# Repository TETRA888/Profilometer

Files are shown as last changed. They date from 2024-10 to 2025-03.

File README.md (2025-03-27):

#  <div align = "center">` Open Road Profiler (ORP) `</div>

 
 
 
 
 
 
 
 
 
 
 
An open-source system engineered to accurately map the deterioration of theoretical road designs proposed by Caltrans. Levergaing Class 3B precision laser, High load and Precision Stepper Motor Drivers, Encoders, Proximity sensors, and adjustable lighting to capture sub-millimeter road surface deformations under simulated traffic loads.

<div align="center">
  title image
</div>
<div align = "Center"> Figure 1.0 (Frame with Electronics) </div>

## Table of Contents
- [Purpose](#purpose)
- [How to Get Started](#how-to-get-started)
   - Parts List
- [Software System Design](#software-design)
- [Electrical System Design](#electrical-system-design)
  - Mounted Electronics
- [Mechanical Design](#mechanical-frame)
  - Assembled Frame
  - CAD model
- [Core Team](#core-team)
- [Documentation](#documentation-and-implementation)
- [Future Work](#future-work)
## Purpose

Purpose-built to work with the **Heavy Vehicle Simulator (HVS) system**, the ORP delivers end-to-end **systems engineering** for tracking pavement wear under simulated traffic conditions. Through repeated verification via external encoder sensors and validation via a 24/7 HVS Crew, the ORP system collects accurate degradation metrics, creating highly detailed point clouds and digital maps of road surfaces. These insights are pivotal in optimizing roads for the state of California. The end goal of this project is to enable all road research labs in the world with the ability to accurately assess how their road design degrades and performs overtime.

<p align="center">
  1-s2 0-S1996681417300354-gr6
</p>
<div align="center"> Figure 2.0 (Heavy Vehicle Simulator @ UCPRC Davis, CA 2025) </div>

<div style="text-align" align = "center">
  
  <div>Figure 2.1</div>

  
  <div>Figure 2.2</div>
</div>

<div style="text-align" align = "center"">
  Paving new Caltrans Proposed Road Designs @ UCPRC Davis, CA 2024
</div>

## How to Get Started
1. Clone the repository
```bash
$ git clone https://github.com/TETRA888/Profilometer.git
$ cd Profilometer
```
2. Download required dependencies 
```bash
$ pip install pyserial
$ pip install pillow
$ pip install pandas
$ pip install numpy
$ pip install matplotlib
$ pip install scipy
```

3. Adjust parameters for serial connection
* Inside /Profilometer/Code/Software/utilityFunctions.py
* Change the first argument for Serial '/dev/cu.usbmodem1422201' to your specific device port name
```python
   return serial.Serial('/dev/cu.usbmodem1422201', 115200, timeout=1)
```

5. Set up the hardware as described in the [Electrical System Design](#electrical-system-design) and [Mechanical Frame](#mechanical-frame) sections.
* [Parts list](https://docs.google.com/spreadsheets/d/1ZoPqY9_Fw6rnbfQ8UKPL65L5WncEJa40W8i2KiA_dJQ/edit?gid=0#gid=0)

## Software Design
The software is written in Python and C/C++ and provides tools for:
* Real-time data acquisition.
* Calibrating tools 
* Exporting data to formats like CSV and STL.

<p align="center">
 software design overview
 simple gui
</p>
<div align ="center"> Software Design Overview/Simple Gui 1.1</div>

## Electrical System Design

The profilometer consists of the following major electronic components:
* Sensors: Class 3B Precision laser, High Resolution Taiss Rotary Encoder, Inductive Proximity Sensor.
* Motors and Power: Nema 23 Stepper Motor, 600W Universal power supply, 5 DC-DC Buck Converters
*	Controllers: Arduino Mega microntroller with Raspberry Pi.

<p align="center">
  System Design
  Electrical Schematic
</p>
<div align="center"> Figure 3.1 High-Level Electrical System Design/Schematic  </div>

<p align="center">
  System Design
</p>
<div align="center"> Figure 3.2 (Assembled electronics) </div>

## Mechanical Frame

The mechanical frame of the profilometer serves as the structure that supports all the components, ensuring stability and precision during measurements. Below are the key aspects of the frame:

Material:
*	Constructed from high-strength aluminum alloy for durability and minimal thermal expansion.
*	Lightweight yet rigid enough to maintain precision during operation.

Design:
*	Modular design to allow for easy assembly and future upgrades.
*	Includes adjustable components to accommodate different sensor configurations and sample sizes.
  
Accessibility and Maintenance:
*	Open design for easy access to internal components, making maintenance and calibration straightforward.
*	Cable management system to keep wiring organized and prevent interference.

<p align="center">
  System Design
</p>
<div align = "Center" > Figure 4.1 (3D Blender Render) </div>

<p align="center">
  System Design
</p>
<div align = "Center" > Figure 4.2 (2nd Design Iteration Of Frame) </div>

# Core Team
- [<br /><sub><a href="https://github.com/TETRA888">Asad Melibaev</a></sub>](https://github.com/TETRA888/Profilometer)

- [<br /><sub><a href="https://github.com/adamhwu">Adam Wu</a></sub>](https://github.com/TETRA888/Profilometer)

# Documentation and Implementation:
1. [Wiki](https://github.com/TETRA888/Profilometer/wiki)

## Future Data Work Flow: pavement assessment via ML models trained on real world data and synthetic road data
* Real Road Data
To integrate ORP’s point cloud data into OpenUSD, the UsdGeomPoints schema will be used to represent sub-millimeter road surface deformations. Each point will include attributes like position (X,Y,ZX,Y,Z), normals, color, and custom degradation metrics. The data pipeline starts with preprocessing raw outputs from ORP (e.g., .txt, .ply), which are then converted into USD files using Python’s USD libraries. Surface reconstruction algorithms, such as Poisson reconstruction, can transform point clouds into detailed meshes stored as UsdGeomMesh. Time-series visualization of road degradation over simulated traffic cycles will leverage USD’s animation capabilities, enabling dynamic analysis. Once generated, USD files can be validated with tools like USDView or NVIDIA Omniverse for real-time visualization and shared for collaborative research. This pipeline enables scalable, accurate modeling of road performance, paving the way for global adoption in road research. Furthermore, OpenUSD could perhaps be even used to generate synthetic data. A similar usecase for generating synthetic data for license plate detection using OpenUSD is showcased here:https://developer.nvidia.com/blog/developing-smart-city-traffic-management-systems-with-openusd-and-synthetic-data/
* Synthetic road data could be generated after importing the profiled road data into OpenUSD. Randomization could be performed to generate more data for road edge cases, following this work flow from the official Nvidia docs:


## Acknowledgements

We would like to thank the following for their contributions to this project:
* Open-Source Libraries: This project uses several open-source libraries (check the dependencies section for a full list).
* Contributors: Thank you to everyone who has contributed to the development of this profilometer. See the contributors page for a list of all contributors.
* Issues: Feel free to open an issue in this GitHub repository for bug reports or feature requests.

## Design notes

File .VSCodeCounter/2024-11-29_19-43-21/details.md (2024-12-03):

# Details

Date : 2024-11-29 19:43:21

Directory d:\\Desktop\\ProfilometerProject\\Code

Total : 35 files,  631 codes, 125 comments, 223 blanks, all 979 lines

[Summary](results.md) / Details / [Diff Summary](diff.md) / [Diff Details](diff-details.md)

## Files
| filename | language | code | comment | blank | total |
| :--- | :--- | ---: | ---: | ---: | ---: |
| [Code/.VSCodeCounter/2024-11-29_19-42-19/details.md](/Code/.VSCodeCounter/2024-11-29_19-42-19/details.md) | Markdown | 27 | 0 | 6 | 33 |
| [Code/.VSCodeCounter/2024-11-29_19-42-19/diff-details.md](/Code/.VSCodeCounter/2024-11-29_19-42-19/diff-details.md) | Markdown | 9 | 0 | 6 | 15 |
| [Code/.VSCodeCounter/2024-11-29_19-42-19/diff.md](/Code/.VSCodeCounter/2024-11-29_19-42-19/diff.md) | Markdown | 12 | 0 | 7 | 19 |
| [Code/.VSCodeCounter/2024-11-29_19-42-19/results.json](/Code/.VSCodeCounter/2024-11-29_19-42-19/results.json) | JSON | 1 | 0 | 0 | 1 |
| [Code/.VSCodeCounter/2024-11-29_19-42-19/results.md](/Code/.VSCodeCounter/2024-11-29_19-42-19/results.md) | Markdown | 21 | 0 | 7 | 28 |
| [Code/.VSCodeCounter/2024-11-29_19-42-25/details.md](/Code/.VSCodeCounter/2024-11-29_19-42-25/details.md) | Markdown | 11 | 0 | 6 | 17 |
| [Code/.VSCodeCounter/2024-11-29_19-42-25/diff-details.md](/Code/.VSCodeCounter/2024-11-29_19-42-25/diff-details.md) | Markdown | 29 | 0 | 6 | 35 |
| [Code/.VSCodeCounter/2024-11-29_19-42-25/diff.md](/Code/.VSCodeCounter/2024-11-29_19-42-25/diff.md) | Markdown | 25 | 0 | 7 | 32 |
| [Code/.VSCodeCounter/2024-11-29_19-42-25/results.json](/Code/.VSCodeCounter/2024-11-29_19-42-25/results.json) | JSON | 1 | 0 | 0 | 1 |
| [Code/.VSCodeCounter/2024-11-29_19-42-25/results.md](/Code/.VSCodeCounter/2024-11-29_19-42-25/results.md) | Markdown | 14 | 0 | 7 | 21 |
| [Code/.VSCodeCounter/2024-11-29_19-42-37/details.md](/Code/.VSCodeCounter/2024-11-29_19-42-37/details.md) | Markdown | 27 | 0 | 6 | 33 |
| [Code/.VSCodeCounter/2024-11-29_19-42-37/diff-details.md](/Code/.VSCodeCounter/2024-11-29_19-42-37/diff-details.md) | Markdown | 29 | 0 | 6 | 35 |
| [Code/.VSCodeCounter/2024-11-29_19-42-37/diff.md](/Code/.VSCodeCounter/2024-11-29_19-42-37/diff.md) | Markdown | 24 | 0 | 7 | 31 |
| [Code/.VSCodeCounter/2024-11-29_19-42-37/results.json](/Code/.VSCodeCounter/2024-11-29_19-42-37/results.json) | JSON | 1 | 0 | 0 | 1 |
| [Code/.VSCodeCounter/2024-11-29_19-42-37/results.md](/Code/.VSCodeCounter/2024-11-29_19-42-37/results.md) | Markdown | 21 | 0 | 7 | 28 |
| [Code/Firmware/main/.VSCodeCounter/2024-11-27_22-10-14/details.md](/Code/Firmware/main/.VSCodeCounter/2024-11-27_22-10-14/details.md) | Markdown | 22 | 0 | 6 | 28 |
| [Code/Firmware/main/.VSCodeCounter/2024-11-27_22-10-14/diff-details.md](/Code/Firmware/main/.VSCodeCounter/2024-11-27_22-10-14/diff-details.md) | Markdown | 9 | 0 | 6 | 15 |
| [Code/Firmware/main/.VSCodeCounter/2024-11-27_22-10-14/diff.md](/Code/Firmware/main/.VSCodeCounter/2024-11-27_22-10-14/diff.md) | Markdown | 12 | 0 | 7 | 19 |
| [Code/Firmware/main/.VSCodeCounter/2024-11-27_22-10-14/results.json](/Code/Firmware/main/.VSCodeCounter/2024-11-27_22-10-14/results.json) | JSON | 1 | 0 | 0 | 1 |
| [Code/Firmware/main/.VSCodeCounter/2024-11-27_22-10-14/results.md](/Code/Firmware/main/.VSCodeCounter/2024-11-27_22-10-14/results.md) | Markdown | 15 | 0 | 7 | 22 |
| [Code/Firmware/main/encoderOutput.cpp](/Code/Firmware/main/encoderOutput.cpp) | C++ | 27 | 11 | 8 | 46 |
| [Code/Firmware/main/encoderOutput.hpp](/Code/Firmware/main/encoderOutput.hpp) | C++ | 11 | 0 | 4 | 15 |
| [Code/Firmware/main/endStopOutput.cpp](/Code/Firmware/main/endStopOutput.cpp) | C++ | 11 | 6 | 7 | 24 |
| [Code/Firmware/main/endStopOutput.hpp](/Code/Firmware/main/endStopOutput.hpp) | C++ | 8 | 0 | 5 | 13 |
| [Code/Firmware/main/laserOutput.cpp](/Code/Firmware/main/laserOutput.cpp) | C++ | 12 | 6 | 5 | 23 |
| [Code/Firmware/main/laserOutput.hpp](/Code/Firmware/main/laserOutput.hpp) | C++ | 9 | 0 | 4 | 13 |
| [Code/Firmware/main/main.ino](/Code/Firmware/main/main.ino) | Arduino | 35 | 10 | 6 | 51 |
| [Code/Firmware/main/statusIndicators.cpp](/Code/Firmware/main/statusIndicators.cpp) | C++ | 46 | 15 | 9 | 70 |
| [Code/Firmware/main/statusIndicators.hpp](/Code/Firmware/main/statusIndicators.hpp) | C++ | 12 | 0 | 6 | 18 |
| [Code/Firmware/main/stepperMotorControl.cpp](/Code/Firmware/main/stepperMotorControl.cpp) | C++ | 22 | 16 | 12 | 50 |
| [Code/Firmware/main/stepperMotorControl.hpp](/Code/Firmware/main/stepperMotorControl.hpp) | C++ | 12 | 0 | 4 | 16 |
| [Code/Firmware/main/utilityFunctions.cpp](/Code/Firmware/main/utilityFunctions.cpp) | C++ | 51 | 17 | 18 | 86 |
| [Code/Firmware/main/utilityFunctions.hpp](/Code/Firmware/main/utilityFunctions.hpp) | C++ | 16 | 0 | 4 | 20 |
| [Code/Software/gui.py](/Code/Software/gui.py) | Python | 21 | 20 | 16 | 57 |
| [Code/Software/utilityFunctions.py](/Code/Software/utilityFunctions.py) | Python | 27 | 24 | 11 | 62 |

[Summary](results.md) / Details / [Diff Summary](diff.md) / [Diff Details](diff-details.md)

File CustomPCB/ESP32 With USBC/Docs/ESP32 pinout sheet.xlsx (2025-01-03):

1 | GND_01
2 | GND_02
3 | 3V3
4 | GPIO0/RTC_GPIO0
5 | GPIO1/RTC_GPIO1/TOUCH1/ADC1_CH0
6 | GPIO2/RTC_GPIO2/TOUCH2/ADC1_CH1
7 | GPIO3/RTC_GPIO3/TOUCH3/ADC1_CH2
8 | GPIO4/RTC_GPIO4/TOUCH4/ADC1_CH3
9 | GPIO5/RTC_GPIO5/TOUCH5/ADC1_CH4
10 | GPIO6/RTC_GPIO6/TOUCH6/ADC1_CH5
11 | GPIO7/RTC_GPIO7/TOUCH7/ADC1_CH6
12 | GPIO8/RTC_GPIO8/TOUCH8/ADC1_CH7/SUBSPICS1
13 | GPIO9/RTC_GPIO9/TOUCH9/ADC1_CH8/FSPIHD/SUBSPIHD
14 | GPIO10/RTC_GPIO10/TOUCH10/ADC1_CH9/FSPICS0/FSPIIO4/SUBSPICS0
15 | GPIO11/RTC_GPIO11/TOUCH11/ADC2_CH0/FSPID/FSPIIO5/SUBSPID
16 | GPIO12/RTC_GPIO12/TOUCH12/ADC2_CH1/FSPICLK/FSPIIO6/SUBSPICLK
17 | GPIO13/RTC_GPIO13/TOUCH13/ADC2_CH2/FSPIQ/FSPIIO7/SUBSPIQ
18 | GPIO14/RTC_GPIO14/TOUCH14/ADC2_CH3/FSPIWP/FSPIDQS/SUBSPIWP
19 | GPIO15/RTC_GPIO15/U0RTS/ADC2_CH4/XTAL_32K_P
20 | GPIO16/RTC_GPIO16/U0CTS/ADC2_CH5/XTAL_32K_N
21 | GPIO17/RTC_GPIO17/U1TXD/ADC2_CH6
22 | GPIO18/RTC_GPIO18/U1RXD/ADC2_CH7/CLK_OUT3
23 | USB_D-/RTC_GPIO19/GPIO19/U1RTS/ADC2_CH8/CLK_OUT2
24 | USB_D+/RTC_GPIO20/GPIO20/U1CTS/ADC2_CH9/CLK_OUT1
25 | GPIO21/RTC_GPIO21
26 | GPIO26/SPICS1
27 | GPIO47/SPICLK_P_DIFF/SUBSPICLK_P_DIFF
28 | GPIO33/SPIIO4/FSPIHD/SUBSPIHD
29 | GPIO34/SPIIO5/FSPICS0/SUBSPICS0
30 | GPIO48/SPICLK_N_DIFF/SUBSPICLK_N_DIFF
31 | GPIO35/SPIIO6/FSPID/SUBSPID
32 | GPIO36/SPIIO7/FSPICLK/SUBSPICLK
33 | GPIO37/SPIDQS/FSPIQ/SUBSPIQ
34 | GPIO38/FSPIWP/SUBSPIWP
35 | MTCK/GPIO39/CLK_OUT3/SUBSPICS1
36 | MTDO/GPIO40/CLK_OUT2
37 | MTDI/GPIO41/CLK_OUT1
38 | MTMS/GPIO42
39 | U0TXD/GPIO43/CLK_OUT1
40 | U0RXD/GPIO44/CLK_OUT2
41 | GPIO45
42 | GND
43 | GND
44 | GPIO46
45 | EN
46 | GND_46
47 | GND_47
48 | GND_48
49 | GND_49
50 | GND_50
51 | GND_51
52 | GND_52
53 | GND_53
54 | GND_54
55 | GND_55
56 | GND_56
57 | GND_57
58 | GND_58
59 | GND_59
60 | GND_60
61 | GND_61
62 | GND_62
63 | GND_63
64 | GND_64
65 | GND_65
66 | GND_66
67 | GND_67
68 | GND_68
69 | GND_69
70 | GND_70
71 | GND_71
72 | GND_72
73 | GND_73

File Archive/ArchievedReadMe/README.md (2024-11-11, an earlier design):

#  <div align="center"> Open Road Profiler (ORP) </div>

The **Open Road Profiler (ORP)** is an advanced, open-source system engineered to map the degradation of theoretical road designs for Caltrans. This precision gantry platform leverages a robust integration of **computer vision**, **LiDAR sensing**, and **optical measurement** technologies, including a Garmin LiDAR-Lite v3HP, a 64MP high-resolution camera, and a Class II precision laser, to capture sub-millimeter road surface deformations under simulated traffic loads.

## Purpose

Purpose-built to work with the **Heavy Vehicle Simulator (HVS) system**, the ORP delivers end-to-end **systems engineering** for tracking pavement wear under simulated traffic conditions. Through repeated verification via external encoder sensors and validation via a 24/7 HVS Crew, the ORP system collects accurate degradation metrics, creating highly detailed point clouds and digital maps of road surfaces. These insights are pivotal in optimizing roads for the state of California. The end goal of this project is to enable all road research labs in the world with the ability to accurately assess how their road design degrades and performs overtime.

## Project Leadership

Led by **Asad Melibaev**, the project emphasizes a modular, scalable design, ensuring smooth integration with existing HVS systems and adaptability to future sensing technologies. With support from a dedicated team of R&D engineers, PhD researchers, and machinists, the ORP’s goal is to enable precise, actionable data analysis to inform road composition improvements and advance Caltrans' pavement research efforts.

<p align="center">
  1-s2 0-S1996681417300354-gr6
</p>
<div align="center"> Figure 1.0 (Heavy Vehicle Simulator) </div>

## Key Contributors

### Core Team
- **Asad Melibaev**  
  *(Systems Lead)*  
  [GitHub Profile](https://github.com/TETRA888)

### Help, Advice and Guidance from
- **Andrew Cobb**  
  *(Sr. Machinst)*  

- **Kin Yen**  
  *(Sr. Development Engineer)*  

- **Stephanus Louw**  
  *(Lead Geotechnical Engineer)*

- **Rauf Zokhrabov**  
  *(Documentation Assistant)*
  *(University of Illinois Urbana-Champaign)*
  
### <div align = "center"> Acknowledgments </div>
I would like to express my sincere gratitude to my Electrical Engineering professors and faculty members at UC Davis for their invaluable support in designing the system and deepening my understanding of circuit design. Their expertise and guidance have been instrumental in the development of this project.
  
## <div align = "center"> Collaborating Institutions </div>
PIC_Logo_Version3-1
cee_logo_125px
ece_logo_125px

# <div align="center"> Asad's Workflow And Design Approach </div>
<p align = "center">
1-s2 0-S1996681417300354-gr6
</p>

### <div align="center"> Figure 2.0 (Asad's Workflow) </div>

# <div align="center"> High-Level Multi System Integration Overview </div>
<p align = "center">
1-s2 0-S1996681417300354-gr6
</p>

### <div align="center"> Figure 3.0 (The connection of different subsystems to collect data on stress tested roads) </div>

# <div align ="center"> High-Level Electrical System Design Overview </div>
ElectricalSystemDiagram(1)
### <div align="center"> Figure 4.0 (Abstract overview of the electronic connections by A.M) </div>

# <div align ="center"> Electronic Schematic Overview </div>

### <div align="center"> Figure 4.1 (Schematic of the single axial gantry control by A.M) </div>

# <div align ="center"> Assembled Data Acquisition Electronics Overview </div>

### <div align="center"> Figure 4.2 (The nervous system of the gantry assembled by A.M) </div>

# <div align ="center"> High-Level Software System Design Overview </div>
<p align = "center">
1-s2 0-S1996681417300354-gr6
</p>

### <div align="center"> Figure 5.0 (Data flow) </div>

## Sample Software Code
```python
import serial
import time
import numpy as np
import open3d as o3d

# Open the serial connection
ser = serial.Serial('/dev/ACM1', 115200, timeout=1)
time.sleep(2)  # Give the connection a moment to initialize

# Send the start command to the Arduino
ser.write(b'START\n')
print("Start command sent to Arduino")

# Function to load point data from a text file
def load_point_data(file_path):
    points_data = np.loadtxt(file_path, delimiter=' ', dtype=float)
    return points_data

# Read the data sent back by the Arduino
data_points = []

while True:
    if ser.in_waiting > 0:
        line = ser.readline().decode('utf-8').strip()
        if line.startswith("DATA:"):
            try:
                _, values = line.split("DATA:")
                x, y, z = map(float, values.split(","))
                print(f"X: {x}, Y: {y}, Z: {z}")
                # Store the data points
                data_points.append((x, y, z))
            except ValueError:
                print("Parsing error!")

    # Break out of the loop if you want to stop reading (you can define a condition)
    if len(data_points) >= 100:  # for example, stop after 100 points
        break

# Convert collected points to NumPy array
points_data = np.array(data_points)

# Ensure the data is in the correct shape
if points_data.shape[1] != 3:
    raise ValueError("Each line in the data must contain 3 values: x, y, z")

# Create Open3D point cloud
pcd = o3d.geometry.PointCloud()
pcd.points = o3d.utility.Vector3dVector(points_data)

# Estimate normals for the point cloud
pcd.estimate_normals(search_param=o3d.geometry.KDTreeSearchParamHybrid(radius=0.1, max_nn=30))

# Perform Poisson reconstruction
mesh, densities = o3d.geometry.TriangleMesh.create_from_point_cloud_poisson(pcd, depth=9)

# Visualize the result
o3d.visualization.draw_geometries([mesh])

# Optionally save the mesh to a file
o3d.io.write_triangle_mesh("output_mesh.ply", mesh)

# Close the serial connection
ser.close()
```

## Sample Firmware Code
```cpp
/*
* Submilimeter X-Axis gantry control code by Asad Melibaev
* This code will be broken down into a multi-file program once debugging and further testing is completed
*/

#include <AccelStepper.h> // Stepper motor library with fine controls
#include <math.h>
#define PI 3.14159265358979323846
#define RC 0.1466275659824047 // Rotary calibration constant calculated by A.M
#define CN 1.33351439541 // Conversion constant calculated by A.M

/*
* Connect corresponding pins to the DM542 stepper motor driver 
*/
const int stepPin = 13;    // STEP pin connected to pin 13
const int dirPin = 12;     // DIR pin connected to pin 12
const int enablePin = 9;   // EN pin connected to pin 9 (optional)

/*
Connect corresponding encoder pins to the microcontroller
*/
const int encoderPinA = 21; // Encoder Channel A
const int encoderPinB = 20; // Encoder Channel B

/*
* Create the stepper object with driver mode enabled by setting the first param to 1
*/
AccelStepper stepper(1, stepPin, dirPin);

/*
* Encoder variables will be constantly changing therefore are set to volatile
* This ensures the compiler does not optimize or store stuff in cache
*/
volatile long encoderPosition = 0; // Current position
volatile bool lastAState = LOW;     // Last state of encoder pin A
volatile int offsetFromExpected = 0;

/*
* Update encoder vars as soon as position changes
*/
void updateEncoder() {
    bool currentAState = digitalRead(encoderPinA);
    bool currentBState = digitalRead(encoderPinB);

    if (currentAState != lastAState) { // Only update on change of state
        if (currentBState == currentAState) {
            encoderPosition++; // Clockwise
        } else {
            encoderPosition--; // Counterclockwise
        }
    }

    lastAState = currentAState; // Update last state

    // Void returns nothin 
}

/*
* Adjusts stepper motor location to correct an offset caused during movement
* @param offsetFromExpected is the amount of steps that the position is offset by
*/
void correctLocation(int offsetFromExpected){
    stepper.moveTo(offsetFromExpected); // Set target position
    while (stepper.distanceToGo() != 0) { // Move until the target position is reached and verified by encoder
        stepper.run(); // Run the stepper motor
    }

    // Void returns nothing
}

/*
* This function verifies that the accuracy is within the submilimeter tolerence and if its not it adjusts the offsetFromExpected value
@ param distance: is the distance in mm
@ param pulses: is the amount of pulses that have been sent to the stepper motor
*/
void verifiedAccuracy(int distance, int pulses){
  double TOLERANCE = 0.1; // in mm

  if (fabs(encoderPosition * RC - distance) > TOLERANCE){
    offsetFromExpected = pulses*CN - encoderPosition;
  }

  // Void Returns nothing
}

/*
* This function moves the rail by the specified distance in mm
@param distance: Is the distance that it will move in mm
*/
void move_rail_x(int distance) {
    int pulses = (distance / (2 * PI * 28)) * 3200; // Calculate pulses for the given distance // 0.1466 mm per pulse to be exact
    stepper.moveTo(pulses); // Set target position
    while (stepper.distanceToGo() != 0) { // Move until the target position is reached and verified by encoder
        stepper.run(); // Run the stepper motor
    }

    /*
    verifiedAccuracy(distance, pulses);

    if (offsetFromExpected != 0){
      correctLocation(offsetFromExpected);
      offsetFromExpected = 0;
    }
    */

    // Void returns nothing
}

/*
* Initialize required pins, interrupts, and serial communication between the PC and microcontroller
*/
void setup() {
    Serial.begin(115200);
    pinMode(enablePin, OUTPUT); // Set the enable pin as an output
    digitalWrite(enablePin, LOW); // Enable the driver
    
    // Set encoder pins as inputs with pull-ups
    pinMode(encoderPinA, INPUT_PULLUP);
    pinMode(encoderPinB, INPUT_PULLUP);
    
    // Attach interrupts for encoder channels
    attachInterrupt(digitalPinToInterrupt(encoderPinA), updateEncoder, CHANGE);
    attachInterrupt(digitalPinToInterrupt(encoderPinB), updateEncoder, CHANGE);

    // Set the maximum speed and acceleration
    stepper.setMaxSpeed(2000); // 2000mm/s
    stepper.setAcceleration(1000); // 400mm/s^2

    // Void returns nothing
}

/*
* Main function where the gantry will move
* Currently setup to check calibration
*/
void loop() {
    int distance = 500; // Distance is in millimeters (1 meter)
    move_rail_x(distance); // Move the rail by the specified distance

    // Optionally, print encoder position for debugging
    Serial.print("Encoder Position: ");
    Serial.print(encoderPosition*RC);
    Serial.println(" mm");
    
    delay(1000); // Wait for 1 second before the next move

    // Void returns nothing
}
```

# <div align ="center"> Mechanical Frame CAD Design Overview </div>
370409415-1df8b744-70b0-4bfa-a11d-afa3a9b27c9c
### <div align = "Center" > Figure 6.0 (3D Blender Render) </div>

## Assembled Sample Frame

### <div align = "Center" > Figure 6.1 (2nd Design Iteration Of Frame) </div>

# Documentation and Implementation:
1. [Wiki](https://github.com/TETRA888/Profilometer/wiki)

# Tech Stack and Specs:
 
 
 
 
 
 
 
 

# Parts:
1. [Exact quantities and parts needed for single axial system](https://docs.google.com/spreadsheets/d/1ZoPqY9_Fw6rnbfQ8UKPL65L5WncEJa40W8i2KiA_dJQ/edit?gid=0#gid=0)
2. [Parts list draft](https://docs.google.com/document/d/1qKMDZtSdquMjX08xfJKCa0uS36UHgNZ3eyHph81zQOM/edit)

# Profiler from 30 years ago
<p align="center"> 

</p>

### <div align = "Center" > Figure 7.0 (The First Profiler) </div>

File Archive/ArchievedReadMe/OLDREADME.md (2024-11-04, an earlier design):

# High-Level Multi System Integration Overview
Systems Diagram(1)

# High-Level Electrical System Design Overview
Electronic System Overview(1)

# High-Level Software System Design Overview
High Level Software

# Low-Level Embedded Software System Design Overview
Software Design

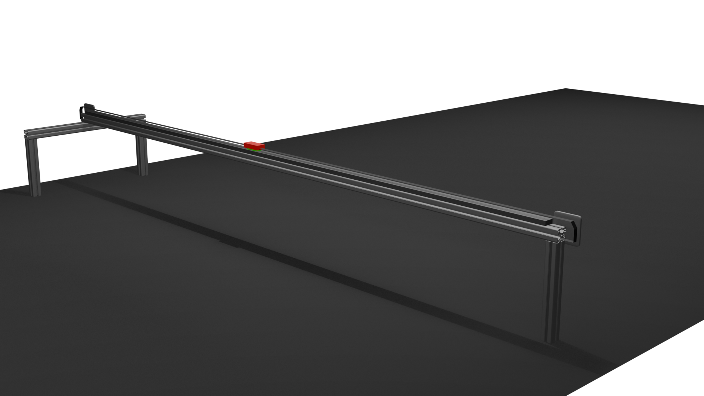
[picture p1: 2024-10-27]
Renders/AngledView.png

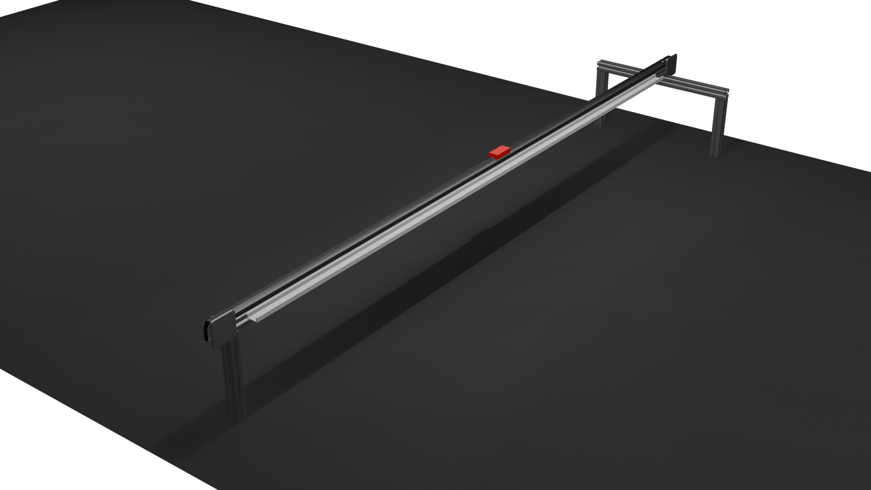
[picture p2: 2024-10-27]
Renders/TopDownView.png

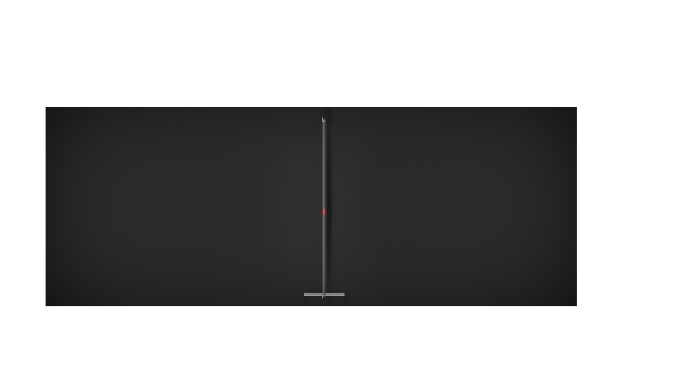
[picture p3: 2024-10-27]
Renders/TopView.png

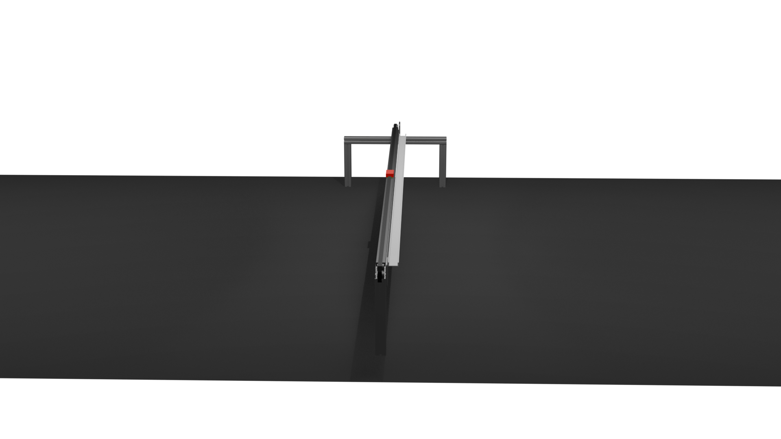
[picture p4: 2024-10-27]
Renders/Sideview.png

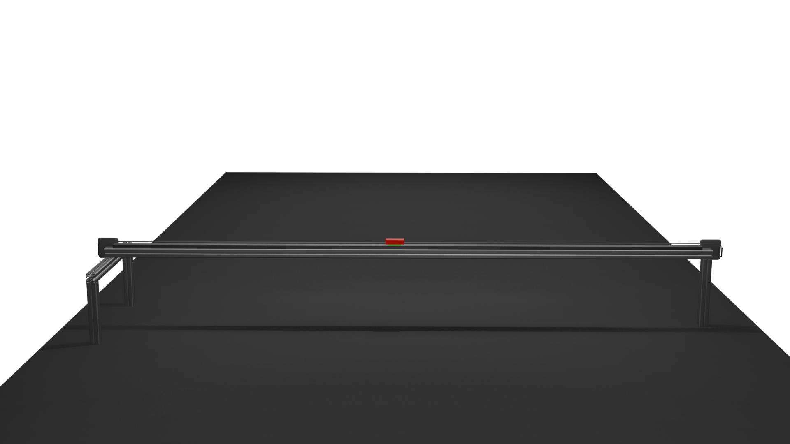
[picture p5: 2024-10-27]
Renders/FrontView.png

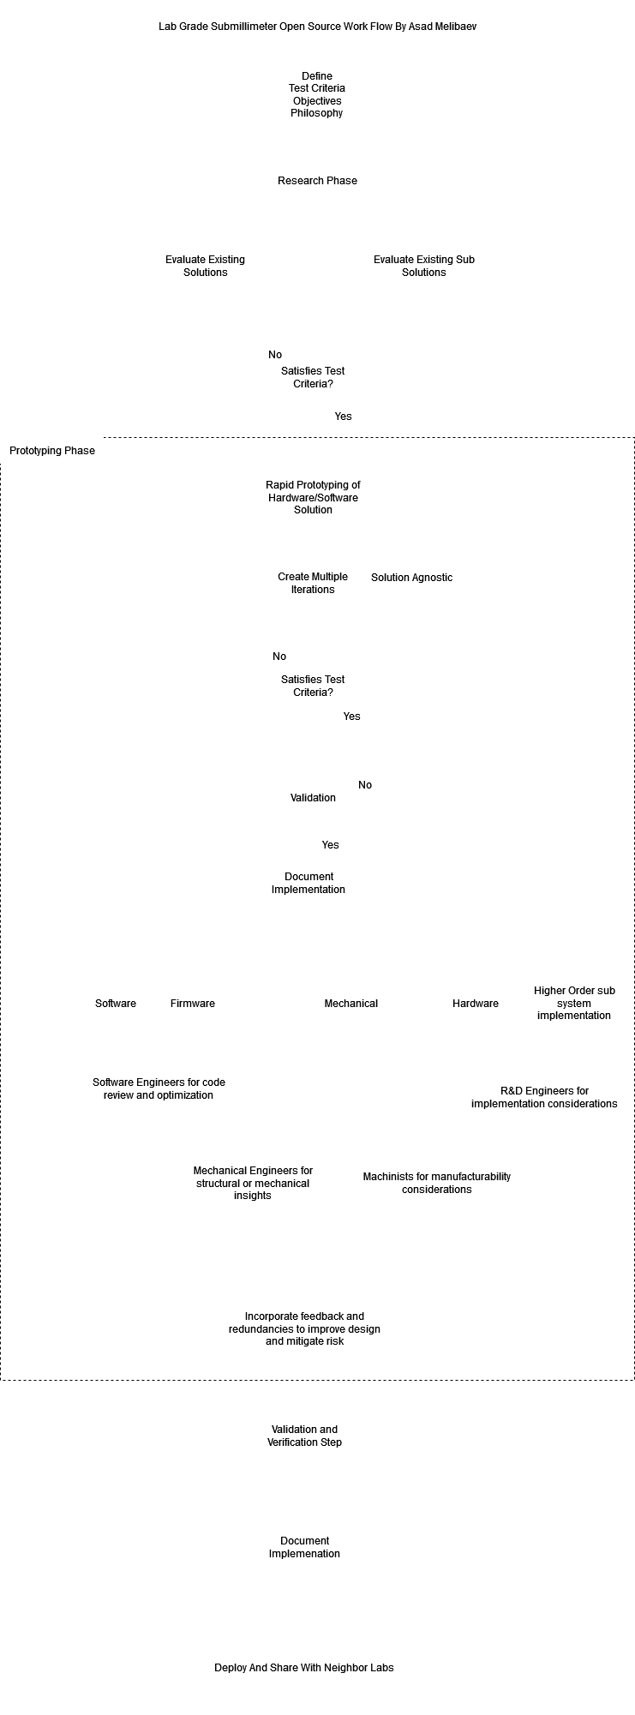
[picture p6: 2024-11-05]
FlowDiagrams/ProcessDiagram.png

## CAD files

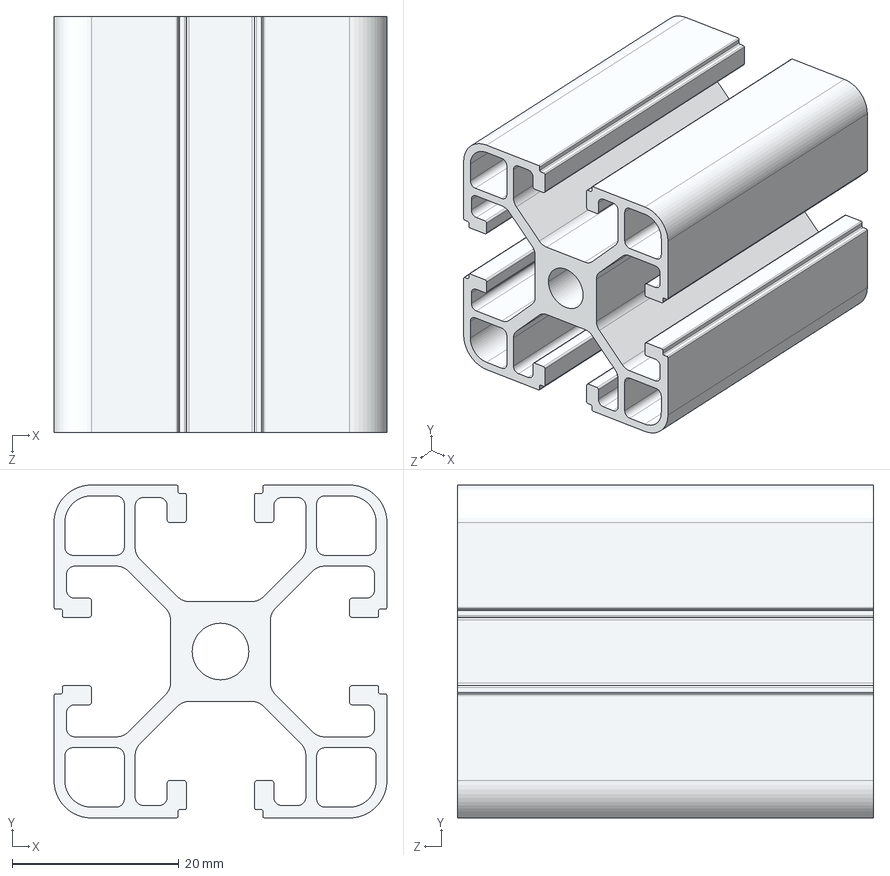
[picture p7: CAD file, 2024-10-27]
CADModels/4040 Aluminum Extrusion Profile.STEP
40.0 x 40.0 x 50.0 mm

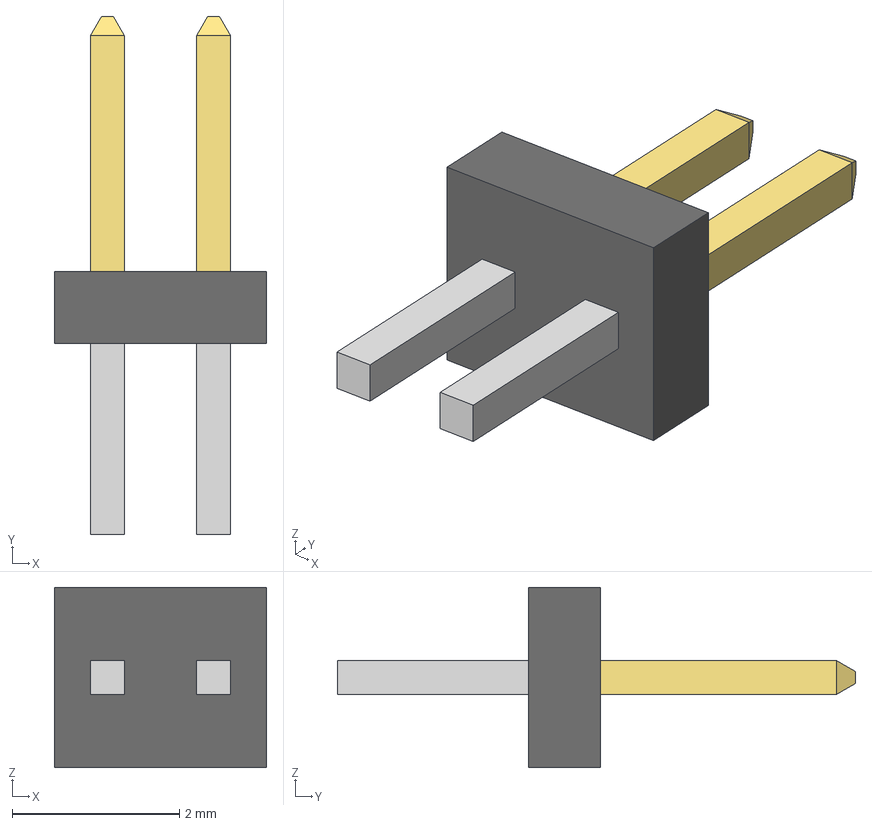
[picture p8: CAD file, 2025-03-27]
CustomPCB/ESP32 With USBC/3D/FTS-102-01-F-S.stp
2.54 x 6.20 x 2.16 mm
FTS-102-01-F-S_body
FTS-102-01-F-S_pins1
FTS-102-01-F-S_pins2

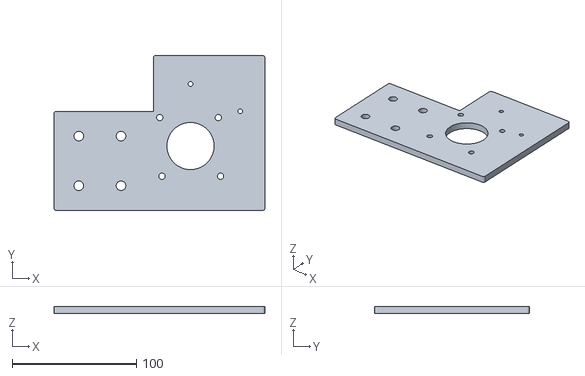
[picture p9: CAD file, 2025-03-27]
ProfilerBrackets/RightSideBracket.stl
170.0 x 125.0 x 6.00

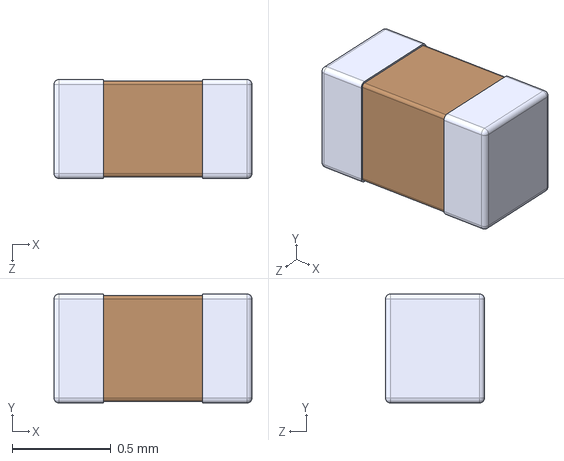
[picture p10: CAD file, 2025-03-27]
CustomPCB/ESP32 With USBC/3D/CL05A105KL5NRNC.step
1.00 x 0.55 x 0.5 mm

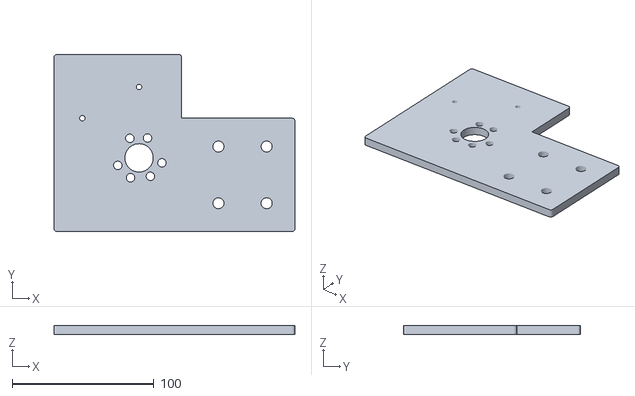
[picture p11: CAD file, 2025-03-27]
ProfilerBrackets/LeftSideBracket.stl
170.0 x 125.0 x 6.00

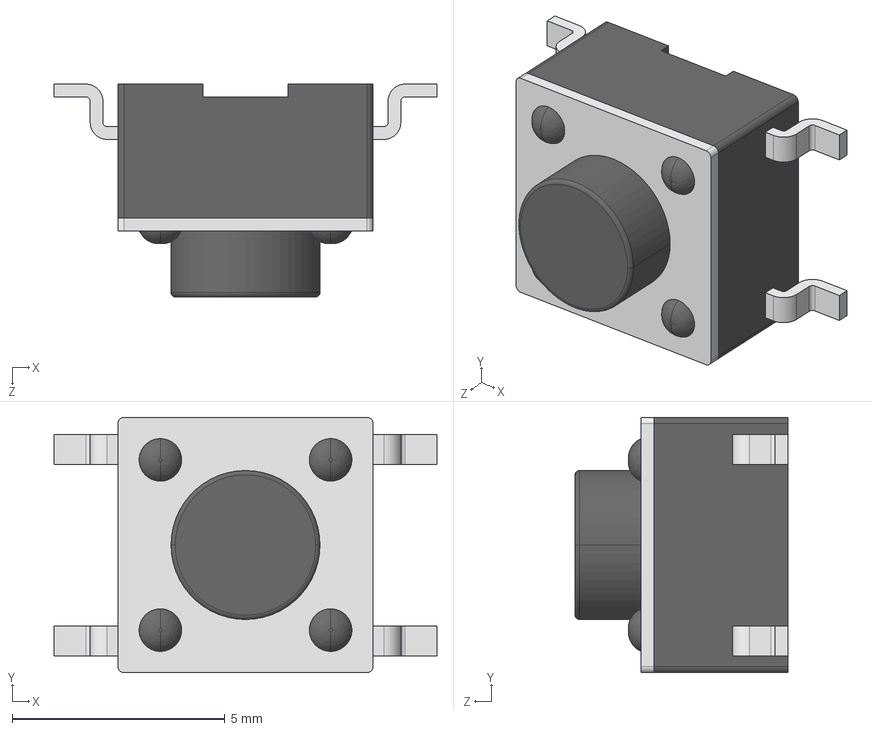
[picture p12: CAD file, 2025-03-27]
CustomPCB/ESP32 With USBC/3D/User Library-PTS645SL50SMTR92-LFS.STEP
9.00 x 6.00 x 5.00 mm

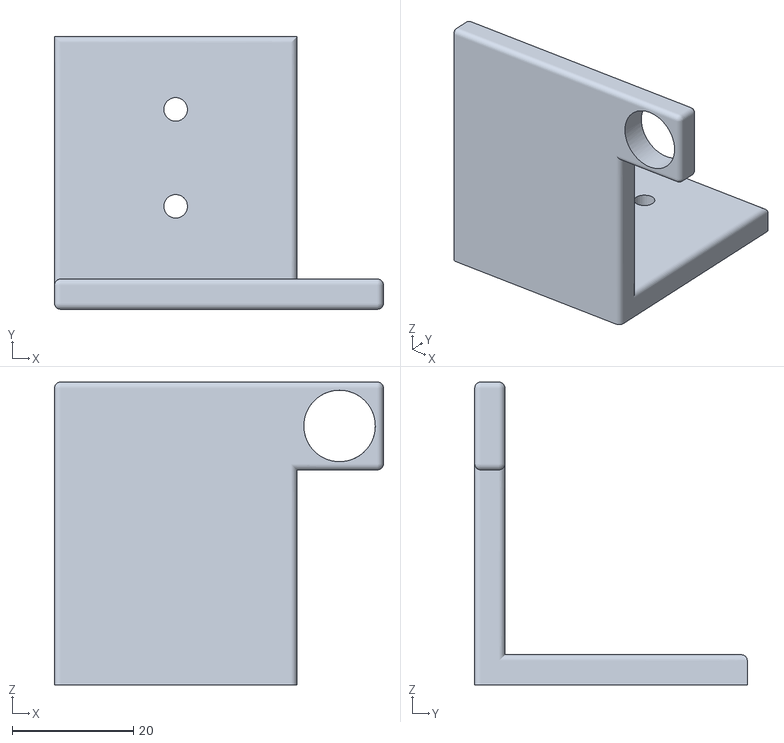
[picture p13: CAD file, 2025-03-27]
ProfilerBrackets/LeftProximityBracket.stl
54.3 x 45.0 x 50.0

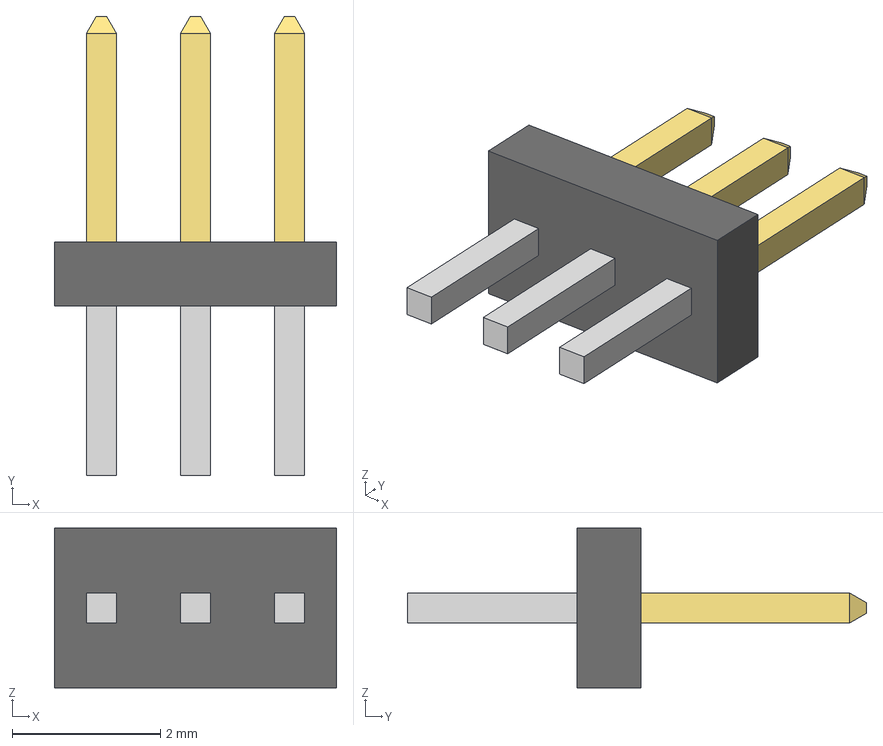
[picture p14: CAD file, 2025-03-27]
CustomPCB/ESP32 With USBC/3D/FTS-103-01-F-S.stp
3.81 x 6.20 x 2.16 mm
FTS-103-01-F-S_body
FTS-103-01-F-S_pins1
FTS-103-01-F-S_pins2

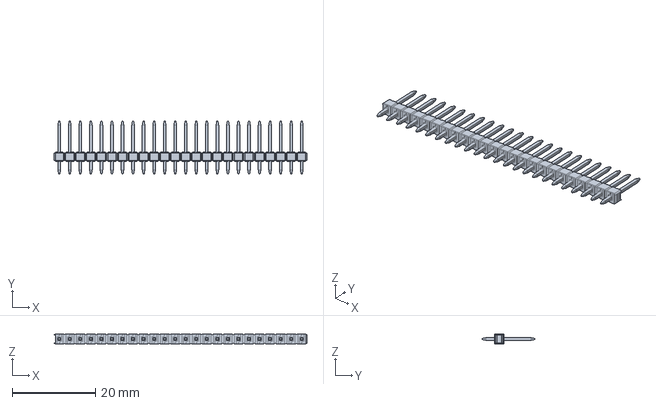
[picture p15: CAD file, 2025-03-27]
CustomPCB/ESP32 With USBC/3D/022284245.stp
61.0 x 12.8 x 2.49 mm

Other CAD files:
ProfilerBrackets/RightProximityBracket.stl
CADModels/4040 Aluminum Extrusion Profile.stl
CADModels/Model.blend

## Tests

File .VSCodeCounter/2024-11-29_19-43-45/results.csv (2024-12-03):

filename | "language" | "Python" | "C++" | "Arduino" | "Markdown" | "JSON" | "comment" | "blank" | "total"
d:\Desktop\ProfilometerProject\Code\Firmware\main\.VSCodeCounter\2024-11-27_22-10-14\details.md | "Markdown" | 0 | 0 | 0 | 22 | 0 | 0 | 6 | 28
d:\Desktop\ProfilometerProject\Code\Firmware\main\.VSCodeCounter\2024-11-27_22-10-14\diff-details.md | "Markdown" | 0 | 0 | 0 | 9 | 0 | 0 | 6 | 15
d:\Desktop\ProfilometerProject\Code\Firmware\main\.VSCodeCounter\2024-11-27_22-10-14\diff.md | "Markdown" | 0 | 0 | 0 | 12 | 0 | 0 | 7 | 19
d:\Desktop\ProfilometerProject\Code\Firmware\main\.VSCodeCounter\2024-11-27_22-10-14\results.json | "JSON" | 0 | 0 | 0 | 0 | 1 | 0 | 0 | 1
d:\Desktop\ProfilometerProject\Code\Firmware\main\.VSCodeCounter\2024-11-27_22-10-14\results.md | "Markdown" | 0 | 0 | 0 | 15 | 0 | 0 | 7 | 22
d:\Desktop\ProfilometerProject\Code\Firmware\main\encoderOutput.cpp | "C++" | 0 | 27 | 0 | 0 | 0 | 11 | 8 | 46
d:\Desktop\ProfilometerProject\Code\Firmware\main\encoderOutput.hpp | "C++" | 0 | 11 | 0 | 0 | 0 | 0 | 4 | 15
d:\Desktop\ProfilometerProject\Code\Firmware\main\endStopOutput.cpp | "C++" | 0 | 11 | 0 | 0 | 0 | 6 | 7 | 24
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

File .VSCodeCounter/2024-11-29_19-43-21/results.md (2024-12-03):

# Summary

Date : 2024-11-29 19:43:21

Directory d:\\Desktop\\ProfilometerProject\\Code

Total : 35 files,  631 codes, 125 comments, 223 blanks, all 979 lines

Summary / [Details](details.md) / [Diff Summary](diff.md) / [Diff Details](diff-details.md)

## Languages
| language | files | code | comment | blank | total |
| :--- | ---: | ---: | ---: | ---: | ---: |
| Markdown | 16 | 307 | 0 | 104 | 411 |
| C++ | 12 | 237 | 71 | 86 | 394 |
| Python | 2 | 48 | 44 | 27 | 119 |
| Arduino | 1 | 35 | 10 | 6 | 51 |
| JSON | 4 | 4 | 0 | 0 | 4 |

## Directories
| path | files | code | comment | blank | total |
| :--- | ---: | ---: | ---: | ---: | ---: |
| . | 35 | 631 | 125 | 223 | 979 |
| .VSCodeCounter | 15 | 252 | 0 | 78 | 330 |
| .VSCodeCounter\\2024-11-29_19-42-19 | 5 | 70 | 0 | 26 | 96 |
| .VSCodeCounter\\2024-11-29_19-42-25 | 5 | 80 | 0 | 26 | 106 |
| .VSCodeCounter\\2024-11-29_19-42-37 | 5 | 102 | 0 | 26 | 128 |
| Firmware | 18 | 331 | 81 | 118 | 530 |
| Firmware\\main | 18 | 331 | 81 | 118 | 530 |
| Firmware\\main (Files) | 13 | 272 | 81 | 92 | 445 |
| Firmware\\main\\.VSCodeCounter | 5 | 59 | 0 | 26 | 85 |
| Firmware\\main\\.VSCodeCounter\\2024-11-27_22-10-14 | 5 | 59 | 0 | 26 | 85 |
| Software | 2 | 48 | 44 | 27 | 119 |

Summary / [Details](details.md) / [Diff Summary](diff.md) / [Diff Details](diff-details.md)

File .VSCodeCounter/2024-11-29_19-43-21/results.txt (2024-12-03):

Date : 2024-11-29 19:43:21
Directory : d:\Desktop\ProfilometerProject\Code
Total : 35 files,  631 codes, 125 comments, 223 blanks, all 979 lines

Languages
+----------+------------+------------+------------+------------+------------+
| language | files      | code       | comment    | blank      | total      |
+----------+------------+------------+------------+------------+------------+
| Markdown |         16 |        307 |          0 |        104 |        411 |
| C++      |         12 |        237 |         71 |         86 |        394 |
| Python   |          2 |         48 |         44 |         27 |        119 |
| Arduino  |          1 |         35 |         10 |          6 |         51 |
| JSON     |          4 |          4 |          0 |          0 |          4 |
+----------+------------+------------+------------+------------+------------+

Directories
+------------------------------------------------------------------------------------------------------+------------+------------+------------+------------+------------+
| path                                                                                                 | files      | code       | comment    | blank      | total      |
+------------------------------------------------------------------------------------------------------+------------+------------+------------+------------+------------+
| .                                                                                                    |         35 |        631 |        125 |        223 |        979 |
| .VSCodeCounter                                                                                       |         15 |        252 |          0 |         78 |        330 |
| .VSCodeCounter\2024-11-29_19-42-19                                                                   |          5 |         70 |          0 |         26 |         96 |
| .VSCodeCounter\2024-11-29_19-42-25                                                                   |          5 |         80 |          0 |         26 |        106 |
| .VSCodeCounter\2024-11-29_19-42-37                                                                   |          5 |        102 |          0 |         26 |        128 |
| Firmware                                                                                             |         18 |        331 |         81 |        118 |        530 |
| Firmware\main                                                                                        |         18 |        331 |         81 |        118 |        530 |
| Firmware\main (Files)                                                                                |         13 |        272 |         81 |         92 |        445 |
| Firmware\main\.VSCodeCounter                                                                         |          5 |         59 |          0 |         26 |         85 |
| Firmware\main\.VSCodeCounter\2024-11-27_22-10-14                                                     |          5 |         59 |          0 |         26 |         85 |
| Software                                                                                             |          2 |         48 |         44 |         27 |        119 |
+------------------------------------------------------------------------------------------------------+------------+------------+------------+------------+------------+

Files
+------------------------------------------------------------------------------------------------------+----------+------------+------------+------------+------------+
| filename                                                                                             | language | code       | comment    | blank      | total      |
+------------------------------------------------------------------------------------------------------+----------+------------+------------+------------+------------+
| d:\Desktop\ProfilometerProject\Code\.VSCodeCounter\2024-11-29_19-42-19\details.md                    | Markdown |         27 |          0 |          6 |         33 |
| d:\Desktop\ProfilometerProject\Code\.VSCodeCounter\2024-11-29_19-42-19\diff-details.md               | Markdown |          9 |          0 |          6 |         15 |
| d:\Desktop\ProfilometerProject\Code\.VSCodeCounter\2024-11-29_19-42-19\diff.md                       | Markdown |         12 |          0 |          7 |         19 |
| d:\Desktop\ProfilometerProject\Code\.VSCodeCounter\2024-11-29_19-42-19\results.json                  | JSON     |          1 |          0 |          0 |          1 |
| d:\Desktop\ProfilometerProject\Code\.VSCodeCounter\2024-11-29_19-42-19\results.md                    | Markdown |         21 |          0 |          7 |         28 |
| d:\Desktop\ProfilometerProject\Code\.VSCodeCounter\2024-11-29_19-42-25\details.md                    | Markdown |         11 |          0 |          6 |         17 |
| d:\Desktop\ProfilometerProject\Code\.VSCodeCounter\2024-11-29_19-42-25\diff-details.md               | Markdown |         29 |          0 |          6 |         35 |
| d:\Desktop\ProfilometerProject\Code\.VSCodeCounter\2024-11-29_19-42-25\diff.md                       | Markdown |         25 |          0 |          7 |         32 |
| d:\Desktop\ProfilometerProject\Code\.VSCodeCounter\2024-11-29_19-42-25\results.json                  | JSON     |          1 |          0 |          0 |          1 |
| d:\Desktop\ProfilometerProject\Code\.VSCodeCounter\2024-11-29_19-42-25\results.md                    | Markdown |         14 |          0 |          7 |         21 |
| d:\Desktop\ProfilometerProject\Code\.VSCodeCounter\2024-11-29_19-42-37\details.md                    | Markdown |         27 |          0 |          6 |         33 |
| d:\Desktop\ProfilometerProject\Code\.VSCodeCounter\2024-11-29_19-42-37\diff-details.md               | Markdown |         29 |          0 |          6 |         35 |
| d:\Desktop\ProfilometerProject\Code\.VSCodeCounter\2024-11-29_19-42-37\diff.md                       | Markdown |         24 |          0 |          7 |         31 |
| d:\Desktop\ProfilometerProject\Code\.VSCodeCounter\2024-11-29_19-42-37\results.json                  | JSON     |          1 |          0 |          0 |          1 |
| d:\Desktop\ProfilometerProject\Code\.VSCodeCounter\2024-11-29_19-42-37\results.md                    | Markdown |         21 |          0 |          7 |         28 |
| d:\Desktop\ProfilometerProject\Code\Firmware\main\.VSCodeCounter\2024-11-27_22-10-14\details.md      | Markdown |         22 |          0 |          6 |         28 |
| d:\Desktop\ProfilometerProject\Code\Firmware\main\.VSCodeCounter\2024-11-27_22-10-14\diff-details.md | Markdown |          9 |          0 |          6 |         15 |
| d:\Desktop\ProfilometerProject\Code\Firmware\main\.VSCodeCounter\2024-11-27_22-10-14\diff.md         | Markdown |         12 |          0 |          7 |         19 |
| d:\Desktop\ProfilometerProject\Code\Firmware\main\.VSCodeCounter\2024-11-27_22-10-14\results.json    | JSON     |          1 |          0 |          0 |          1 |
| d:\Desktop\ProfilometerProject\Code\Firmware\main\.VSCodeCounter\2024-11-27_22-10-14\results.md      | Markdown |         15 |          0 |          7 |         22 |
| d:\Desktop\ProfilometerProject\Code\Firmware\main\encoderOutput.cpp                                  | C++      |         27 |         11 |          8 |         46 |
| d:\Desktop\ProfilometerProject\Code\Firmware\main\encoderOutput.hpp                                  | C++      |         11 |          0 |          4 |         15 |
| d:\Desktop\ProfilometerProject\Code\Firmware\main\endStopOutput.cpp                                  | C++      |         11 |          6 |          7 |         24 |
| d:\Desktop\ProfilometerProject\Code\Firmware\main\endStopOutput.hpp                                  | C++      |          8 |          0 |          5 |         13 |
| d:\Desktop\ProfilometerProject\Code\Firmware\main\laserOutput.cpp                                    | C++      |         12 |          6 |          5 |         23 |
| d:\Desktop\ProfilometerProject\Code\Firmware\main\laserOutput.hpp                                    | C++      |          9 |          0 |          4 |         13 |
| d:\Desktop\ProfilometerProject\Code\Firmware\main\main.ino                                           | Arduino  |         35 |         10 |          6 |         51 |
| d:\Desktop\ProfilometerProject\Code\Firmware\main\statusIndicators.cpp                               | C++      |         46 |         15 |          9 |         70 |
| d:\Desktop\ProfilometerProject\Code\Firmware\main\statusIndicators.hpp                               | C++      |         12 |          0 |          6 |         18 |
| d:\Desktop\ProfilometerProject\Code\Firmware\main\stepperMotorControl.cpp                            | C++      |         22 |         16 |         12 |         50 |
| d:\Desktop\ProfilometerProject\Code\Firmware\main\stepperMotorControl.hpp                            | C++      |         12 |          0 |          4 |         16 |
| d:\Desktop\ProfilometerProject\Code\Firmware\main\utilityFunctions.cpp                               | C++      |         51 |         17 |         18 |         86 |
| d:\Desktop\ProfilometerProject\Code\Firmware\main\utilityFunctions.hpp                               | C++      |         16 |          0 |          4 |         20 |
| d:\Desktop\ProfilometerProject\Code\Software\gui.py                                                  | Python   |         21 |         20 |         16 |         57 |
| d:\Desktop\ProfilometerProject\Code\Software\utilityFunctions.py                                     | Python   |         27 |         24 |         11 |         62 |
| Total                                                                                                |          |        631 |        125 |        223 |        979 |
+------------------------------------------------------------------------------------------------------+----------+------------+------------+------------+------------+

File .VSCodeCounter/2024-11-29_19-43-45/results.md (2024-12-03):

# Summary

Date : 2024-11-29 19:43:45

Directory d:\\Desktop\\ProfilometerProject\\Code

Total : 20 files,  379 codes, 125 comments, 145 blanks, all 649 lines

Summary / [Details](details.md) / [Diff Summary](diff.md) / [Diff Details](diff-details.md)

## Languages
| language | files | code | comment | blank | total |
| :--- | ---: | ---: | ---: | ---: | ---: |
| C++ | 12 | 237 | 71 | 86 | 394 |
| Markdown | 4 | 58 | 0 | 26 | 84 |
| Python | 2 | 48 | 44 | 27 | 119 |
| Arduino | 1 | 35 | 10 | 6 | 51 |
| JSON | 1 | 1 | 0 | 0 | 1 |

## Directories
| path | files | code | comment | blank | total |
| :--- | ---: | ---: | ---: | ---: | ---: |
| . | 20 | 379 | 125 | 145 | 649 |
| Firmware | 18 | 331 | 81 | 118 | 530 |
| Firmware\\main | 18 | 331 | 81 | 118 | 530 |
| Firmware\\main (Files) | 13 | 272 | 81 | 92 | 445 |
| Firmware\\main\\.VSCodeCounter | 5 | 59 | 0 | 26 | 85 |
| Firmware\\main\\.VSCodeCounter\\2024-11-27_22-10-14 | 5 | 59 | 0 | 26 | 85 |
| Software | 2 | 48 | 44 | 27 | 119 |

Summary / [Details](details.md) / [Diff Summary](diff.md) / [Diff Details](diff-details.md)

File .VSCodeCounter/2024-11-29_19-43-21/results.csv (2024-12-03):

filename | "language" | "Python" | "C++" | "Markdown" | "JSON" | "Arduino" | "comment" | "blank" | "total"
d:\Desktop\ProfilometerProject\Code\.VSCodeCounter\2024-11-29_19-42-19\details.md | "Markdown" | 0 | 0 | 27 | 0 | 0 | 0 | 6 | 33
d:\Desktop\ProfilometerProject\Code\.VSCodeCounter\2024-11-29_19-42-19\diff-details.md | "Markdown" | 0 | 0 | 9 | 0 | 0 | 0 | 6 | 15
d:\Desktop\ProfilometerProject\Code\.VSCodeCounter\2024-11-29_19-42-19\diff.md | "Markdown" | 0 | 0 | 12 | 0 | 0 | 0 | 7 | 19
d:\Desktop\ProfilometerProject\Code\.VSCodeCounter\2024-11-29_19-42-19\results.json | "JSON" | 0 | 0 | 0 | 1 | 0 | 0 | 0 | 1
d:\Desktop\ProfilometerProject\Code\.VSCodeCounter\2024-11-29_19-42-19\results.md | "Markdown" | 0 | 0 | 21 | 0 | 0 | 0 | 7 | 28
d:\Desktop\ProfilometerProject\Code\.VSCodeCounter\2024-11-29_19-42-25\details.md | "Markdown" | 0 | 0 | 11 | 0 | 0 | 0 | 6 | 17
d:\Desktop\ProfilometerProject\Code\.VSCodeCounter\2024-11-29_19-42-25\diff-details.md | "Markdown" | 0 | 0 | 29 | 0 | 0 | 0 | 6 | 35
d:\Desktop\ProfilometerProject\Code\.VSCodeCounter\2024-11-29_19-42-25\diff.md | "Markdown" | 0 | 0 | 25 | 0 | 0 | 0 | 7 | 32
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

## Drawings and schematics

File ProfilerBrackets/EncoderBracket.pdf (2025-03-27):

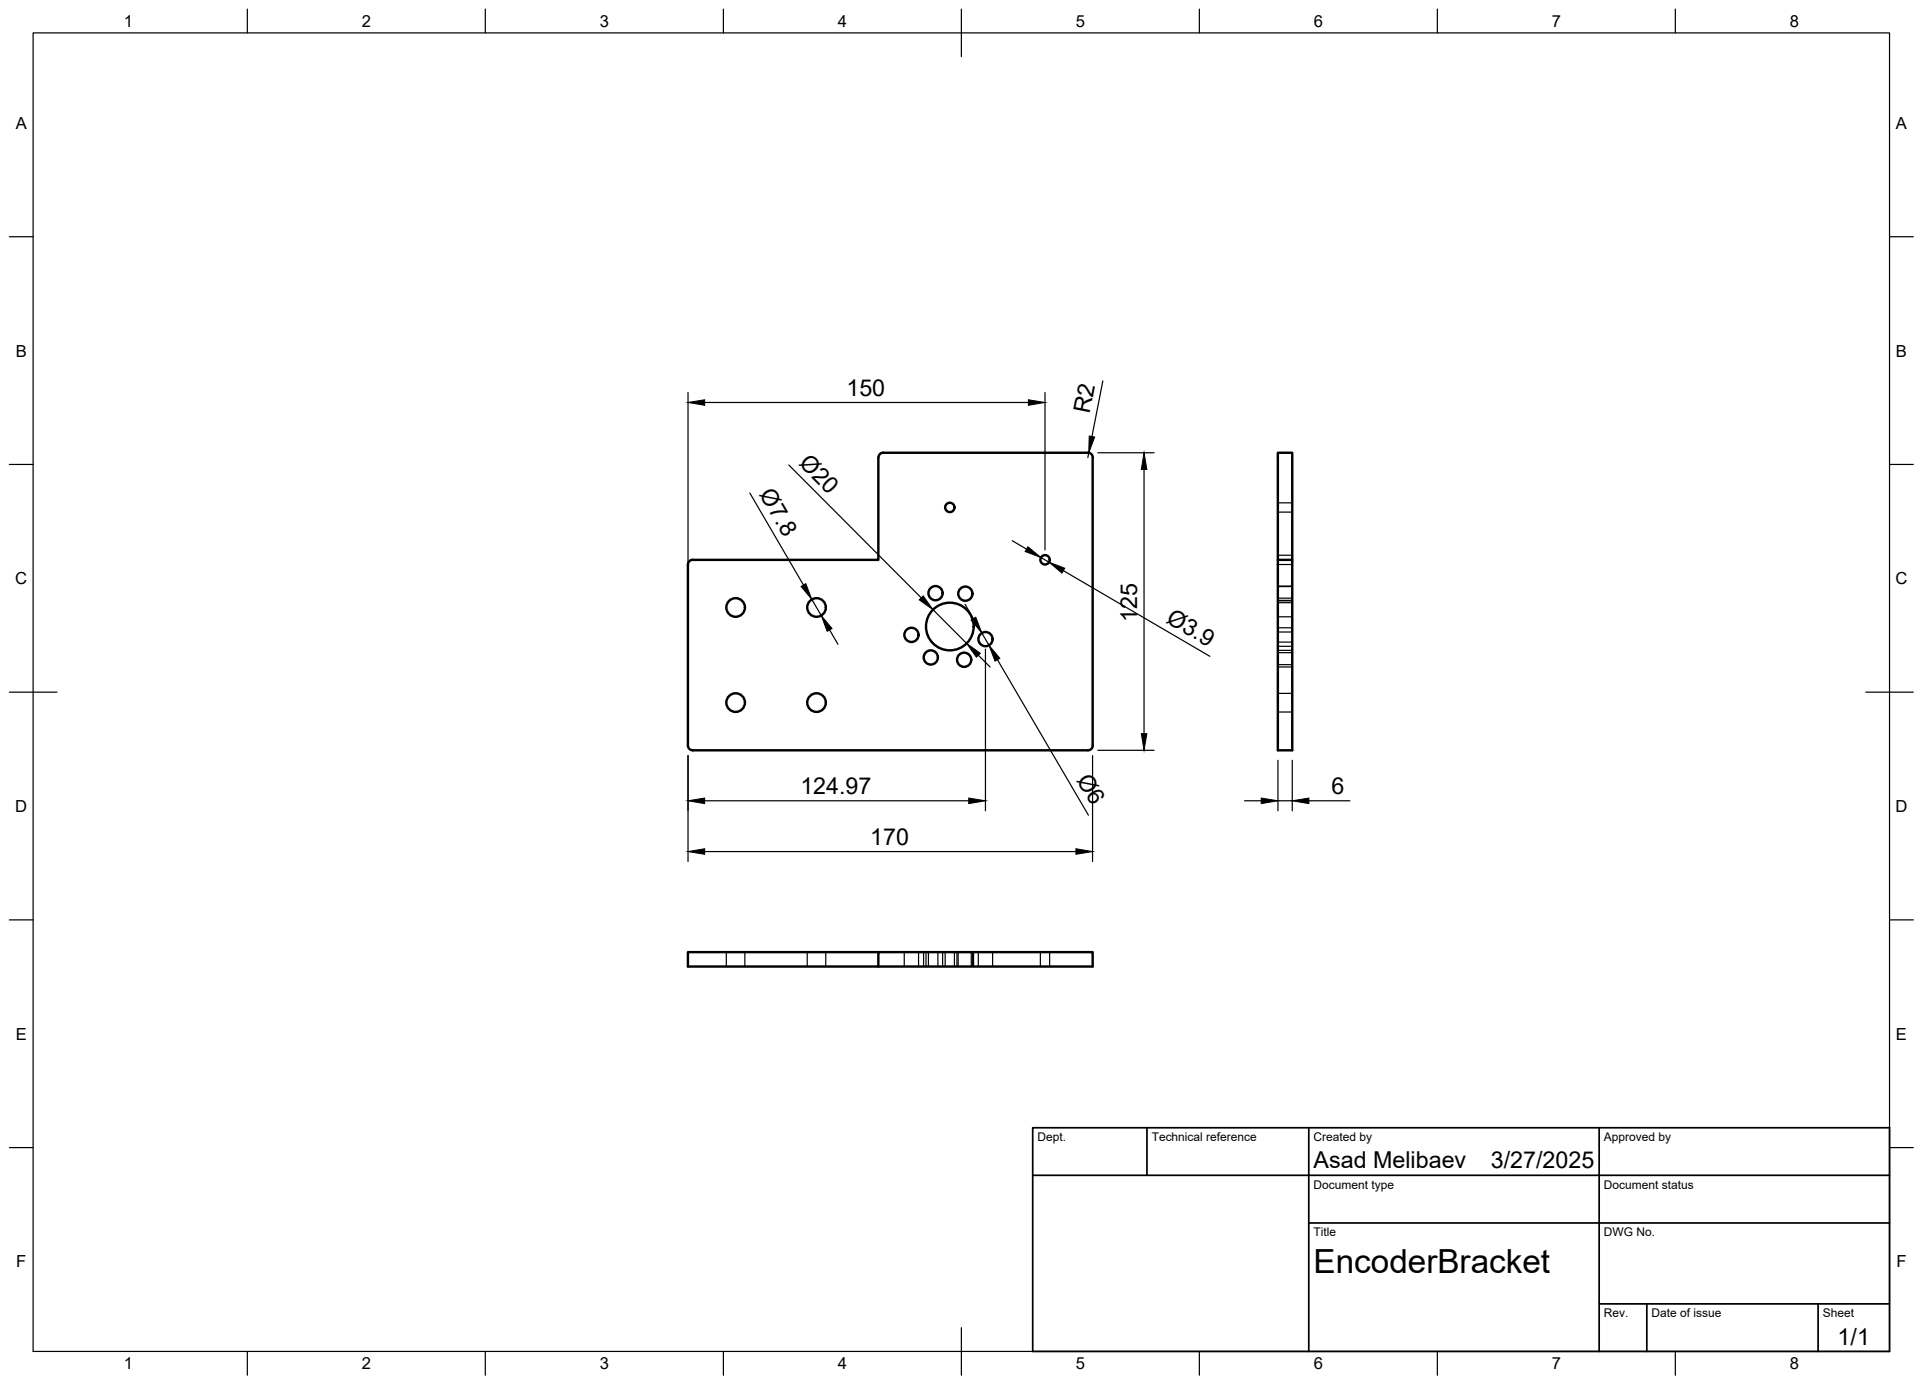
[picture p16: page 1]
Title; DWG No.; Rev.; Date of issue; Sheet

Dept. | Technical reference | Created by Asad Melibaev 3/27/2025 | Approved by

Document type | Document status

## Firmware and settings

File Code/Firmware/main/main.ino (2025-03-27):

#include "stepperMotorControl.hpp"
#include "endStopOutput.hpp"
#include "encoderOutput.hpp"
#include "laserOutput.hpp"
#include "statusIndicators.hpp"
#include "utilityFunctions.hpp"

/*
    This is the main setup function which will setup the peripherals of all of the functions

    The current version of the profiler has the following hardware:
    - 2x Proximity sensors for end stops on both ends of the rail
    - 1x Rotary encoder for the rail to check for accurate movement
    - 1x High Torque NEMA 23 stepper motor for the axis
    - 1x Laser sensor for the profiler to measure the distance
    - 3x Indicator lights to indicate the status of the profiler

    NOTES:
    The rotary encoder will only be used during the calibration check of the profiler to ensure that the system is calibrated

    @author Asad Melibaev <amelibaev@ucdavis.edu>
    @version 2.0
    @since: 2025-21-09
*/

/*
  The setup function is where the setup functions of the peripherals will be called
*/
void setup(){
    Serial.begin(115200); // Begin serial communication at 115200 bits per second

    /*
      @param speed Setting speed to 2000 mm/s
      @param acceleration Setting acceleration to 1000mm/s^2
    */
    setupStepperMotors(2000, 1000);

    setupEncoder(); // Setup encoder input pins

    //setupLaser(); // Setup laser sensor       //FIXME WHEN YOU CONNECT A LASER, LIDAR OR ANY OTHER SENSOR

    homeRailX(); // Home the rail

    lightIndicatorSetup(); // setup indicator light inputs pins

    /*
      @param arg0 is the light that you want to turn on
             - 1 is the Green LED
             - 2 is the Yellow LED
             - 3 is the Red LED
      @param arg1 is what state you want the LED to be in
              - 1 is LED ON
              - 0 is LED OFF  
    */
    lightIndicatorActivation(1, 1); // Green light indicating that everything is functioning

    /*
      NOTES:
      The setup laser function only works for the specific KEYENCE LB1000 laser that I setup at the time
      If you are using a different laser sensor, you will need to modify the setupLaser function to accomodate for the different sensor
      You can also write a different function to make it work with your sensor
    */  
}

/*
  A simple function that will turn on only the yellow light to indicate that a function is in progress
*/
void functionInprogress(){
  lightIndicatorActivation(1, 0);
  lightIndicatorActivation(2, 1);
  lightIndicatorActivation(3, 0);
}


/*
  This is where we will be constantly monitoring the actions that the Raspberry Pi is requesting for us to perform
*/
void loop(){

  if (Serial.available() > 0){
    lightIndicatorActivation(1,1); // Turn on green light

    String command = Serial.readStringUntil('\n');

    if(command == "START"){
      functionInprogress();
      collectDataPoints(0, 2500, 0.1); // This is 25000 data points over the span of 2.5 meters
      Serial.println("DATA_COLLECTION_COMPLETE");
    }

    else if (command == "CALIBRATE"){
      functionInprogress();
      if(calibrationCheck()){
        Serial.println("CALIBRATION_SUCCESSFUL");
      }
      else{
        Serial.println("CALIBRATION_FAILED");
      }
    }

    else if (command == "HOME"){
      functionInprogress();
      homeRailX();
      Serial.println("HOME_COMPLETE");
    }

    /* 
    debugging commands
    */
    else if (command == "SCANMOVELESS"){
      functionInprogress();
      scanMoveless(0, 2500, 0.1);
      Serial.println("DATA_COLLECTION_COMPLETE");
    }

    else if (command == "MOVESCANLESS"){
      functionInprogress();
      moveScanless(0, 2500, 0.1);
      Serial.println("DATA_COLLECTION_COMPLETE");
    }
  }

  else{
    lightIndicatorActivation(3,1); // red light if not serial connection is established with Raspberry Pi
  }
}

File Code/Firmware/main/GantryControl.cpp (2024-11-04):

// GantryControl.cpp
#include "GantryControl.h"
#include <math.h>

const uint32_t INFINITY_INT = UINT32_MAX; // 4294967295
const double RC = 0.1466275659824047;     // Rotary calibration constant
const double CN = 1.33351439541; // Rotary Conversion constant
const int stepPin = 13;
const int dirPin = 12;
const int enablePin = 9;
const int encoderPinA = 21;
const int encoderPinB = 20;
const int EndStop0 = 2;
const int EndStop1 = 3;

volatile long encoderPosition = 0; 
volatile bool lastAState = LOW;     
volatile int offsetFromExpected = 0;

AccelStepper stepper(1, stepPin, dirPin);

void updateEncoder() {
    bool currentAState = digitalRead(encoderPinA);
    bool currentBState = digitalRead(encoderPinB);

    if (currentAState != lastAState) {
        if (currentBState == currentAState) {
            encoderPosition++;
        } else {
            encoderPosition--;
        }
    }

    lastAState = currentAState; 
}

void correctLocation(int offsetFromExpected) {
    stepper.moveTo(offsetFromExpected);
    while (stepper.distanceToGo() != 0) {
        stepper.run();
    }
}

void verifiedAccuracy(int distance, int pulses) {
    double TOLERANCE = 0.1; // in mm

    if (fabs(encoderPosition * RC - distance) > TOLERANCE) {
        offsetFromExpected = pulses * CN - encoderPosition;
    }
}

bool move_rail_x(int distance) {
    int pulses = (distance / (2 * PI * 28)) * 3200; 
    stepper.moveTo(pulses);
    while (stepper.distanceToGo() != 0) {
        stepper.run();
    }
    return true; 
}

void setupGantry() {
    pinMode(EndStop0, INPUT);
    pinMode(EndStop1, INPUT);
    pinMode(enablePin, OUTPUT);
    digitalWrite(enablePin, LOW);
    pinMode(encoderPinA, INPUT_PULLUP);
    pinMode(encoderPinB, INPUT_PULLUP);
    
    attachInterrupt(digitalPinToInterrupt(encoderPinA), updateEncoder, CHANGE);
    attachInterrupt(digitalPinToInterrupt(encoderPinB), updateEncoder, CHANGE);

    /*
    * Speed and Acceleration settings all in mm
    */
    stepper.setMaxSpeed(2000);
    stepper.setAcceleration(1000);
}

bool MovementUnitTest(float distance) {
    if (CalibrateSystem()) {
        move_rail_x(distance);
        Serial.print("Encoder Position: ");
        Serial.print(encoderPosition * RC);
        Serial.println(" mm");
        Serial.print("Intended Position: ");
        Serial.print(distance);
        Serial.println(" mm");
        if ((round(encoderPosition * RC * 100.0) / 100.0) == distance)
            Serial.println("Unit test 1 passed");
        return true;
    } else {
        Serial.println("Unit test 1 failed");
        return false;
    }
}

bool CalibrateSystem() {
    int InitialEndStopState = digitalRead(EndStop0);
    int RailDistance = 2500; 
    bool wait = true;
    if (InitialEndStopState == HIGH) {
        while (wait) {
            wait = !(move_rail_x(RailDistance));
        }
        int LastEndStopState = digitalRead(EndStop1);
        if (LastEndStopState == HIGH) {
            move_rail_x(-1 * RailDistance);
            return true;
        } else {
            Serial.println("Positioning verification has failed!!!");
            return false;
        }
    } else {
        Serial.println("Please Move the block to the start position!!!");
        return false;
    }
}

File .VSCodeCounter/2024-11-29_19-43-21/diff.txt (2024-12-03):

Date : 2024-11-29 19:43:21
Directory : d:\Desktop\ProfilometerProject\Code
Total : 0 files,  0 codes, 0 comments, 0 blanks, all 0 lines

Languages
+----------+------------+------------+------------+------------+------------+
| language | files      | code       | comment    | blank      | total      |
+----------+------------+------------+------------+------------+------------+
+----------+------------+------------+------------+------------+------------+

Directories
+------+------------+------------+------------+------------+------------+
| path | files      | code       | comment    | blank      | total      |
+------+------------+------------+------------+------------+------------+
+------+------------+------------+------------+------------+------------+

Files
+----------+----------+------------+------------+------------+------------+
| filename | language | code       | comment    | blank      | total      |
+----------+----------+------------+------------+------------+------------+
| Total    |          |          0 |          0 |          0 |          0 |
+----------+----------+------------+------------+------------+------------+

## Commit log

2024-09-25 Adding Altium Files
    [DM542.SchLib, MotorControl.PcbDoc, MotorControl.SchDoc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]
2024-09-25 Fixed schematic
    [MotorControl.SchDoc, UCPRC_Profilometer.PrjPcb]
2024-10-27 Add renders and models
    [4040 Aluminum Extrusion Profile.STEP, 4040 Aluminum Extrusion Profile.stl, Model.blend]
2024-11-02 Schematic folder added
2024-11-03 Fix schematics
    [BuckConverter.SchLib, CloudStorage.SchDoc, DM542.SchLib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]
2024-11-04 Add laser spec sheet
2024-11-06 Clean up
    [4040 Aluminum Extrusion Profile.STEP, 4040 Aluminum Extrusion Profile.stl, Model.blend]
2024-11-28 upload latest code
    [diff.csv, diff.txt, results.csv]
2024-11-28 upload refined code
    [diff.csv, diff.txt, results.csv]
2024-11-30 Add new gui
    [diff.csv, diff.txt, results.csv]
2024-12-03 Update text
    [diff.csv, diff.txt, results.csv]
2025-01-03 Add Custom PCB
    [217179-0001.PcbLib, 217179-0001.SchLib, ESP32 With USBC.PrjPcb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]
2025-01-31 Update PCB
    [ESP32 with USBC.SchDoc, Schlib.SchLib, output.csv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]
2025-02-02 PCB Updates
    [ESP32 with USBC.SchDoc, SS8050-G.PcbLib, SS8050-G.SchLib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]
2025-02-19 Update Altium Schematic
    [ESP32 With USBC.PrjPcb, ESP32 with USBC.SchDoc, PcbLib.PcbLib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]
2025-03-27 custom pcb
    [022284245.stp, 217179-0001.PcbLib, 217179-0001.SchLib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]
2025-03-27 debugged code
    [LeftProximityBracket.stl, LeftSideBracket.stl, RightProximityBracket.stl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]
2025-03-27 Revised code
    [diff.csv, diff.txt, results.csv]

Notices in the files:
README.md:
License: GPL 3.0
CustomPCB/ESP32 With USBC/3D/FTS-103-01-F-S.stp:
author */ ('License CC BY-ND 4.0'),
